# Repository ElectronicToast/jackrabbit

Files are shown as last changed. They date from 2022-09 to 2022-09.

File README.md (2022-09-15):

# jackrabbit

 

RP2040 16-channel 100 MHz logic analyzer

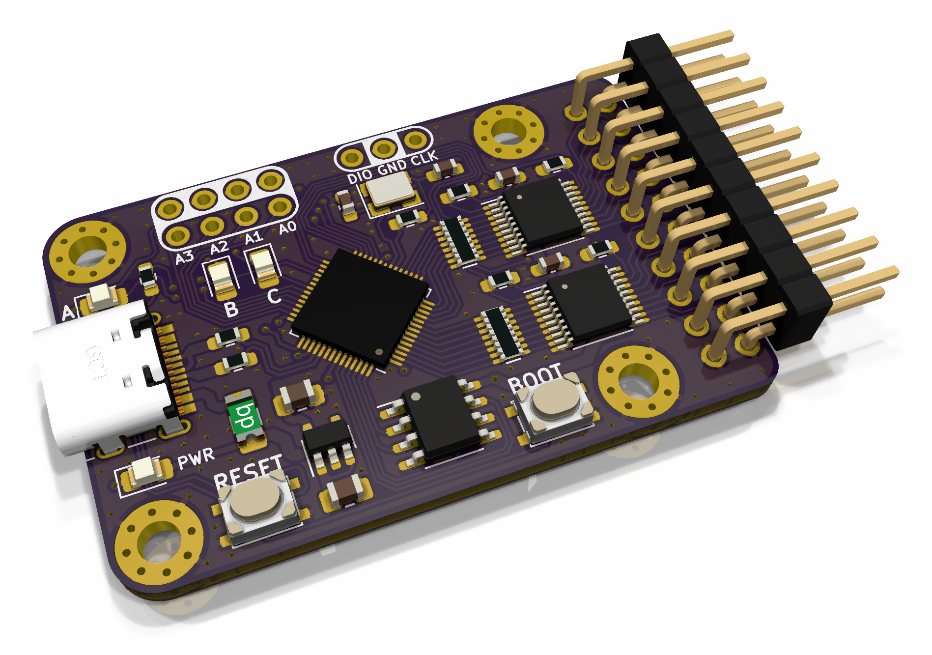
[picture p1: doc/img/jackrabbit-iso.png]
iso


## Description
Jackrabbit is a RP2040-based 16-channel logic analyzer in a tiny 1.8" by 1.2" form factor. All digital inputs are buffered for compatibility with both 3V3 and 5V logic. Boot mode select and reset buttons are provided for convenience, and the ADC inputs and SWD pins are broken out. A USB-C connector is present for firmware updates and serial data.

## Documentation
- [Schematic](https://github.com/ElectronicToast/jackrabbit/blob/main/doc/jackrabbit.pdf)
- Fab print [front](https://github.com/ElectronicToast/jackrabbit/blob/main/doc/jackrabbit-f.pdf) and [back](https://github.com/ElectronicToast/jackrabbit/blob/main/doc/jackrabbit-b.pdf)
- [Interactive BOM](http://htmlpreview.github.io/?https://github.com/ElectronicToast/jackrabbit/blob/main/doc/ibom.html)

## Contributors
- Brian Cruz - BS EE, Caltech, 2023
- Brandon Gong - BS CECS, USC, 2024
- Ray Sun - BS EE, Caltech, 2020; PhD EE, USC, 2026

## Licensing
This project is released under the terms of the MIT License.

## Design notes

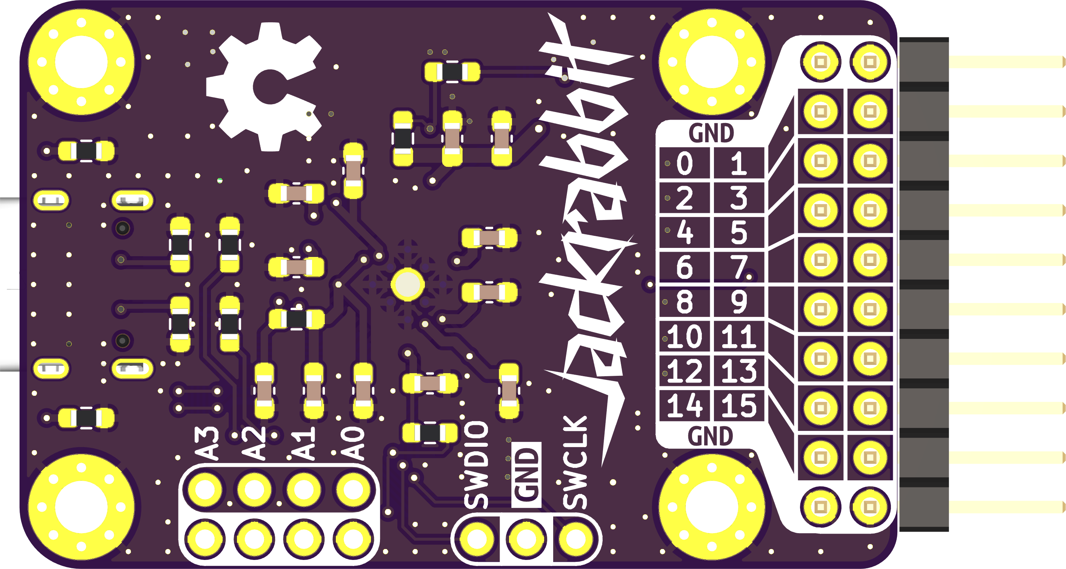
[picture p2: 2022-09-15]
doc/img/jackrabbit-b.png

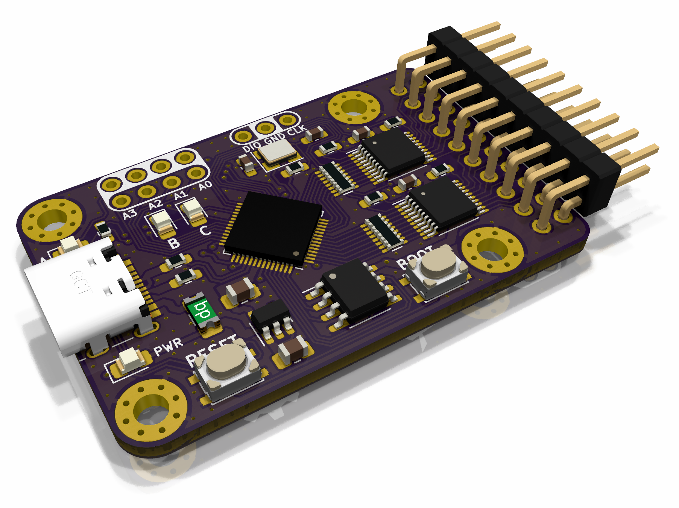
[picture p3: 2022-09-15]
doc/img/jackrabbit-iso1.png

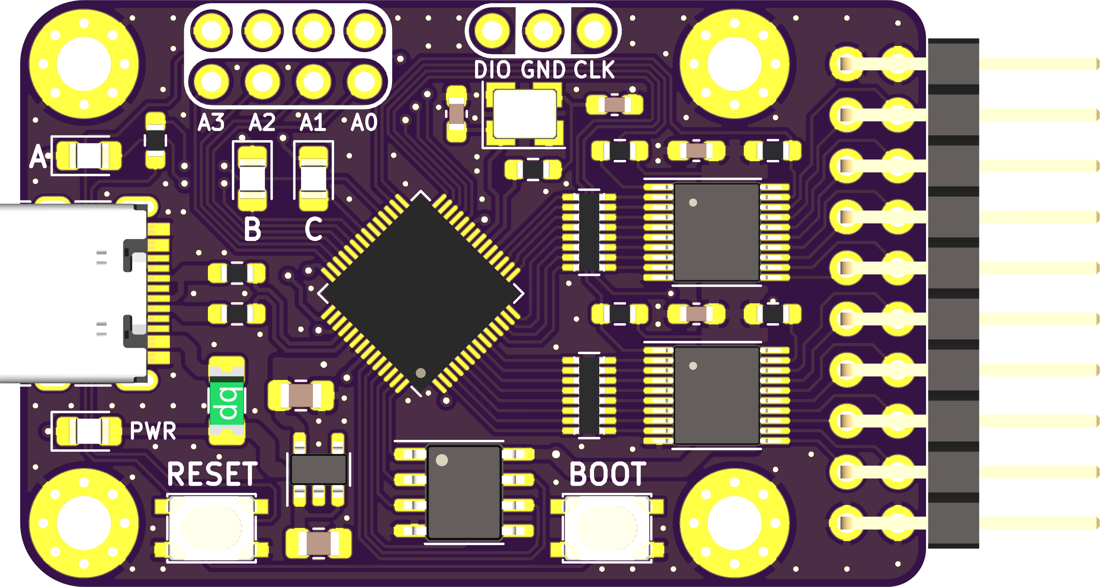
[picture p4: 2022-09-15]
doc/img/jackrabbit-f.png

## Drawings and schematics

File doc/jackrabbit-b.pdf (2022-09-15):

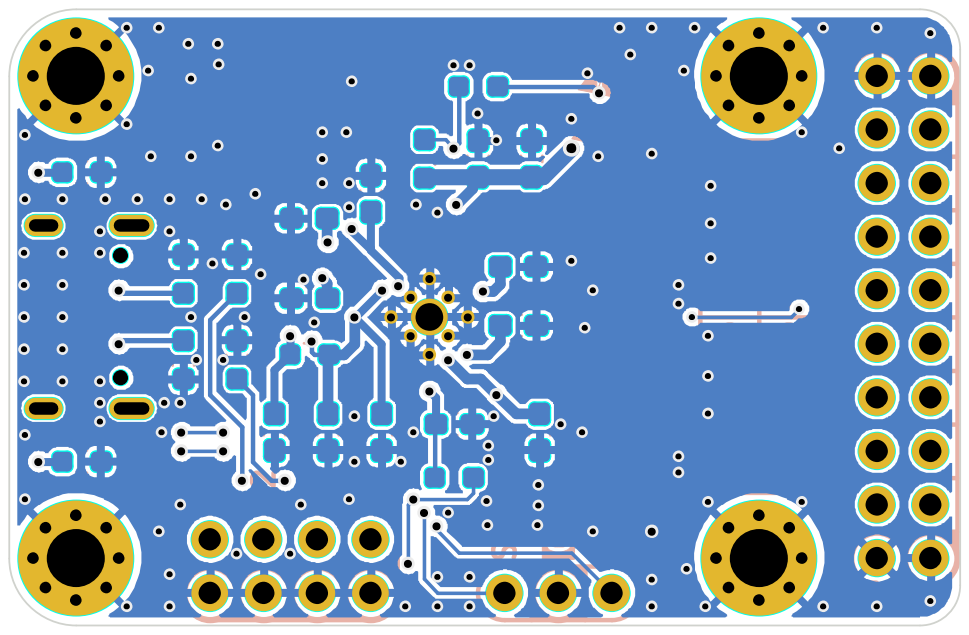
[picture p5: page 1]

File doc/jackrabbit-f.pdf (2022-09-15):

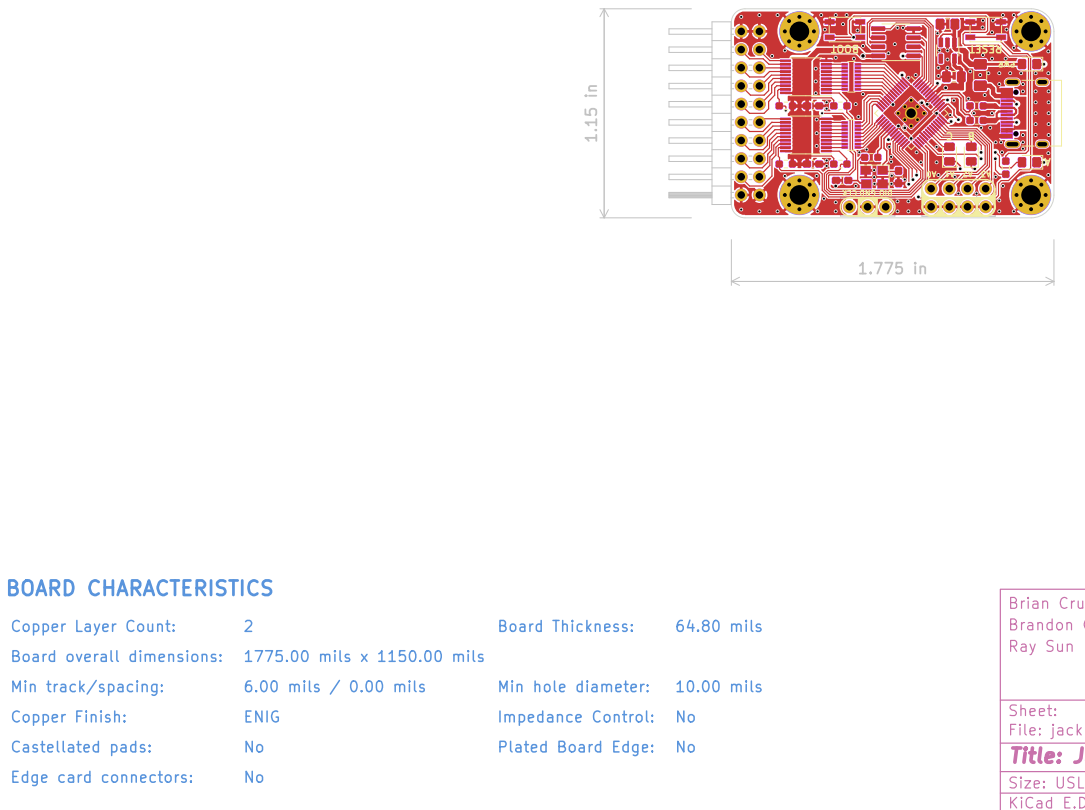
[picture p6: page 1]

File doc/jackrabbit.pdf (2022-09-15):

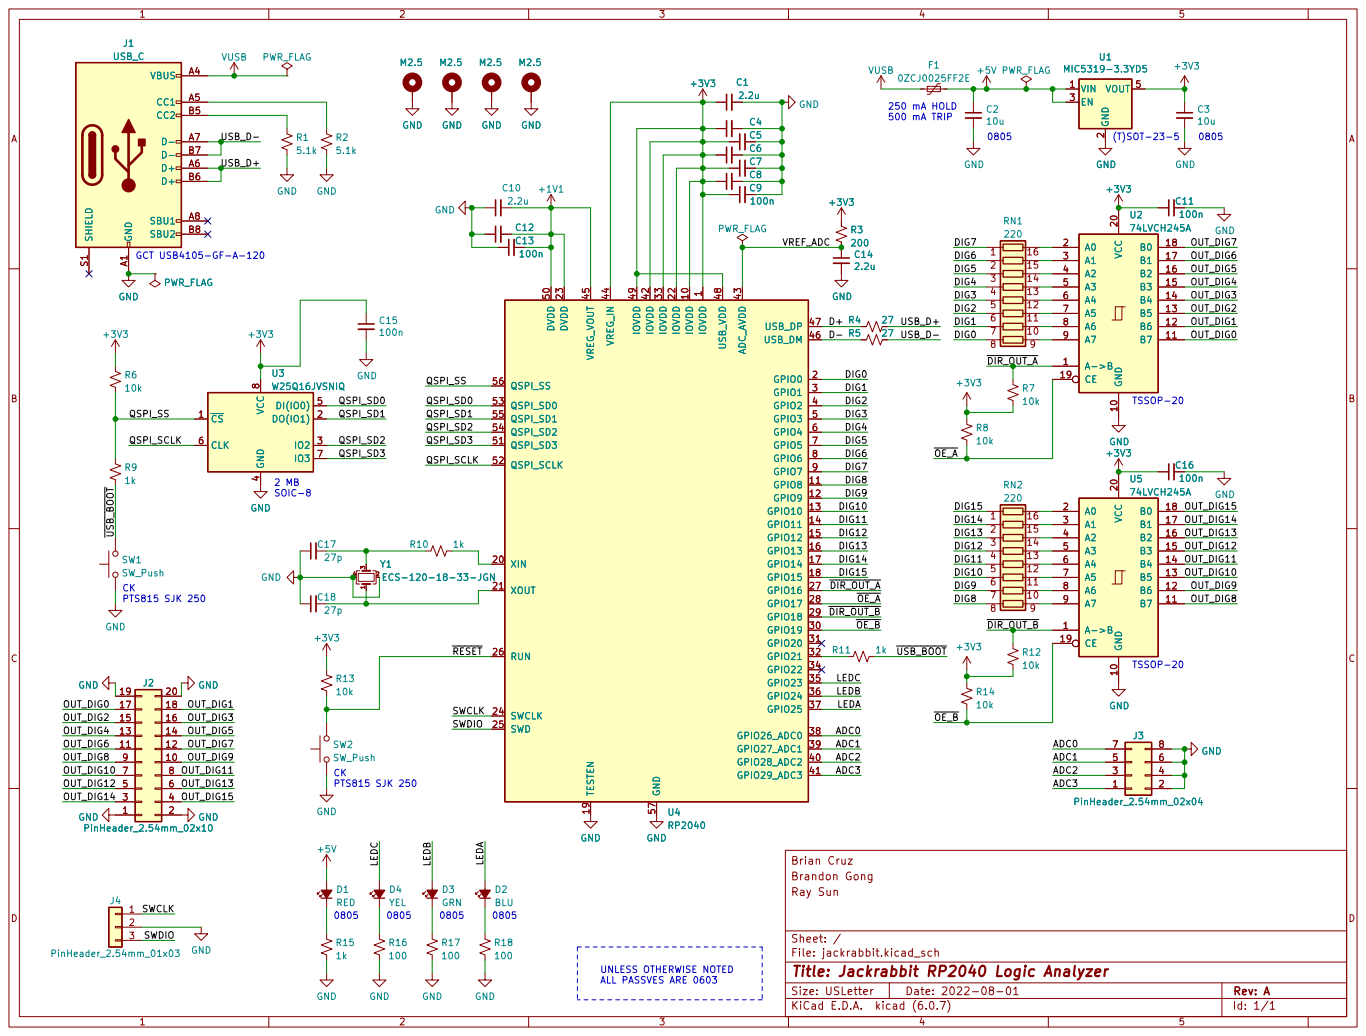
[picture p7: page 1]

1 IOVDD 10 GPIO8 11 GPIO9 12 GPIO10 13 GPIO11 14 GPIO12 15 GPIO13 16 GPIO14 17 GPIO15 18 TESTEN 19 GPIO0 2 XIN 20 XOUT 21 IOVDD 22 DVDD 23 SWCLK 24 SWD 25 RUN 26 GPIO16 27 GPIO17 28 GPIO18 29 GPIO1 3 GPIO19 30 GPIO20 31 GPIO21 32 IOVDD 33 GPIO22 34 GPIO23 35 GPIO24 36 GPIO25 37 GPIO26_ADC0 38 GPIO27_ADC1 39 GPIO2 4 GPIO28_ADC2 40 GPIO29_ADC3 41 IOVDD 42 ADC_AVDD 43 VREG_IN 44 VREG_VOUT 45 USB_DM 46 USB_DP 47 USB_VDD 48 IOVDD 49 GPIO3 5 DVDD 50 QSPI_SD3 51 QSPI_SCLK 52 QSPI_SD0 53 QSPI_SD2 54 QSPI_SD1 55 QSPI_SS 56 GND 57 GPIO4 6 GPIO5 7 GPIO6 8 GPIO7 9 U4RP2040 DIG9 ADC3 OUT_DIG15 ADC2 DIG15 DIG11 DIG10 OUT_DIG10 OUT_DIG9 OUT_DIG8 USB_D+ D- D+ OUT_DIG13 OUT_DIG14 OUT_DIG11 OUT_DIG12 DIG0 USB_D- OUT_DIG0 DIG7 DIG8 DIG9 ~{OE_A} DIG5 DIG6 DIG3 DIG2 DIG4 DIG1 DIG0 ~{DIR_OUT_A} DIG1 DIG11 DIG14 ~{DIR_OUT_B} DIG15 OUT_DIG0 SWDIO

1 IOVDD 10 GPIO8 11 GPIO9 12 GPIO10 13 GPIO11 14 GPIO12 15 GPIO13 16 GPIO14 17 GPIO15 18 TESTEN 19 GPIO0 2 XIN 20 XOUT 21 IOVDD 22 DVDD 23 SWCLK 24 SWD 25 RUN 26 GPIO16 27 GPIO17 28 GPIO18 29 GPIO1 3 GPIO19 30 GPIO20 31 GPIO21 32 IOVDD 33 GPIO22 34 GPIO23 35 GPIO24 36 GPIO25 37 GPIO26_ADC0 38 GPIO27_ADC1 39 GPIO2 4 GPIO28_ADC2 40 GPIO29_ADC3 41 IOVDD 42 ADC_AVDD 43 VREG_IN 44 VREG_VOUT 45 USB_DM 46 USB_DP 47 USB_VDD 48 IOVDD 49 GPIO3 5 DVDD 50 QSPI_SD3 51 QSPI_SCLK 52 QSPI_SD0 53 QSPI_SD2 54 QSPI_SD1 55 QSPI_SS 56 GND 57 GPIO4 6 GPIO5 7 GPIO6 8 GPIO7 9 Y1 ECS-120-18-33-JGN

Brandon Gong Brian Cruz

File: jackrabbit.kicad_sch Sheet: / Ray Sun

Id: 1/1 Title: Jackrabbit RP2040 Logic Analyzer

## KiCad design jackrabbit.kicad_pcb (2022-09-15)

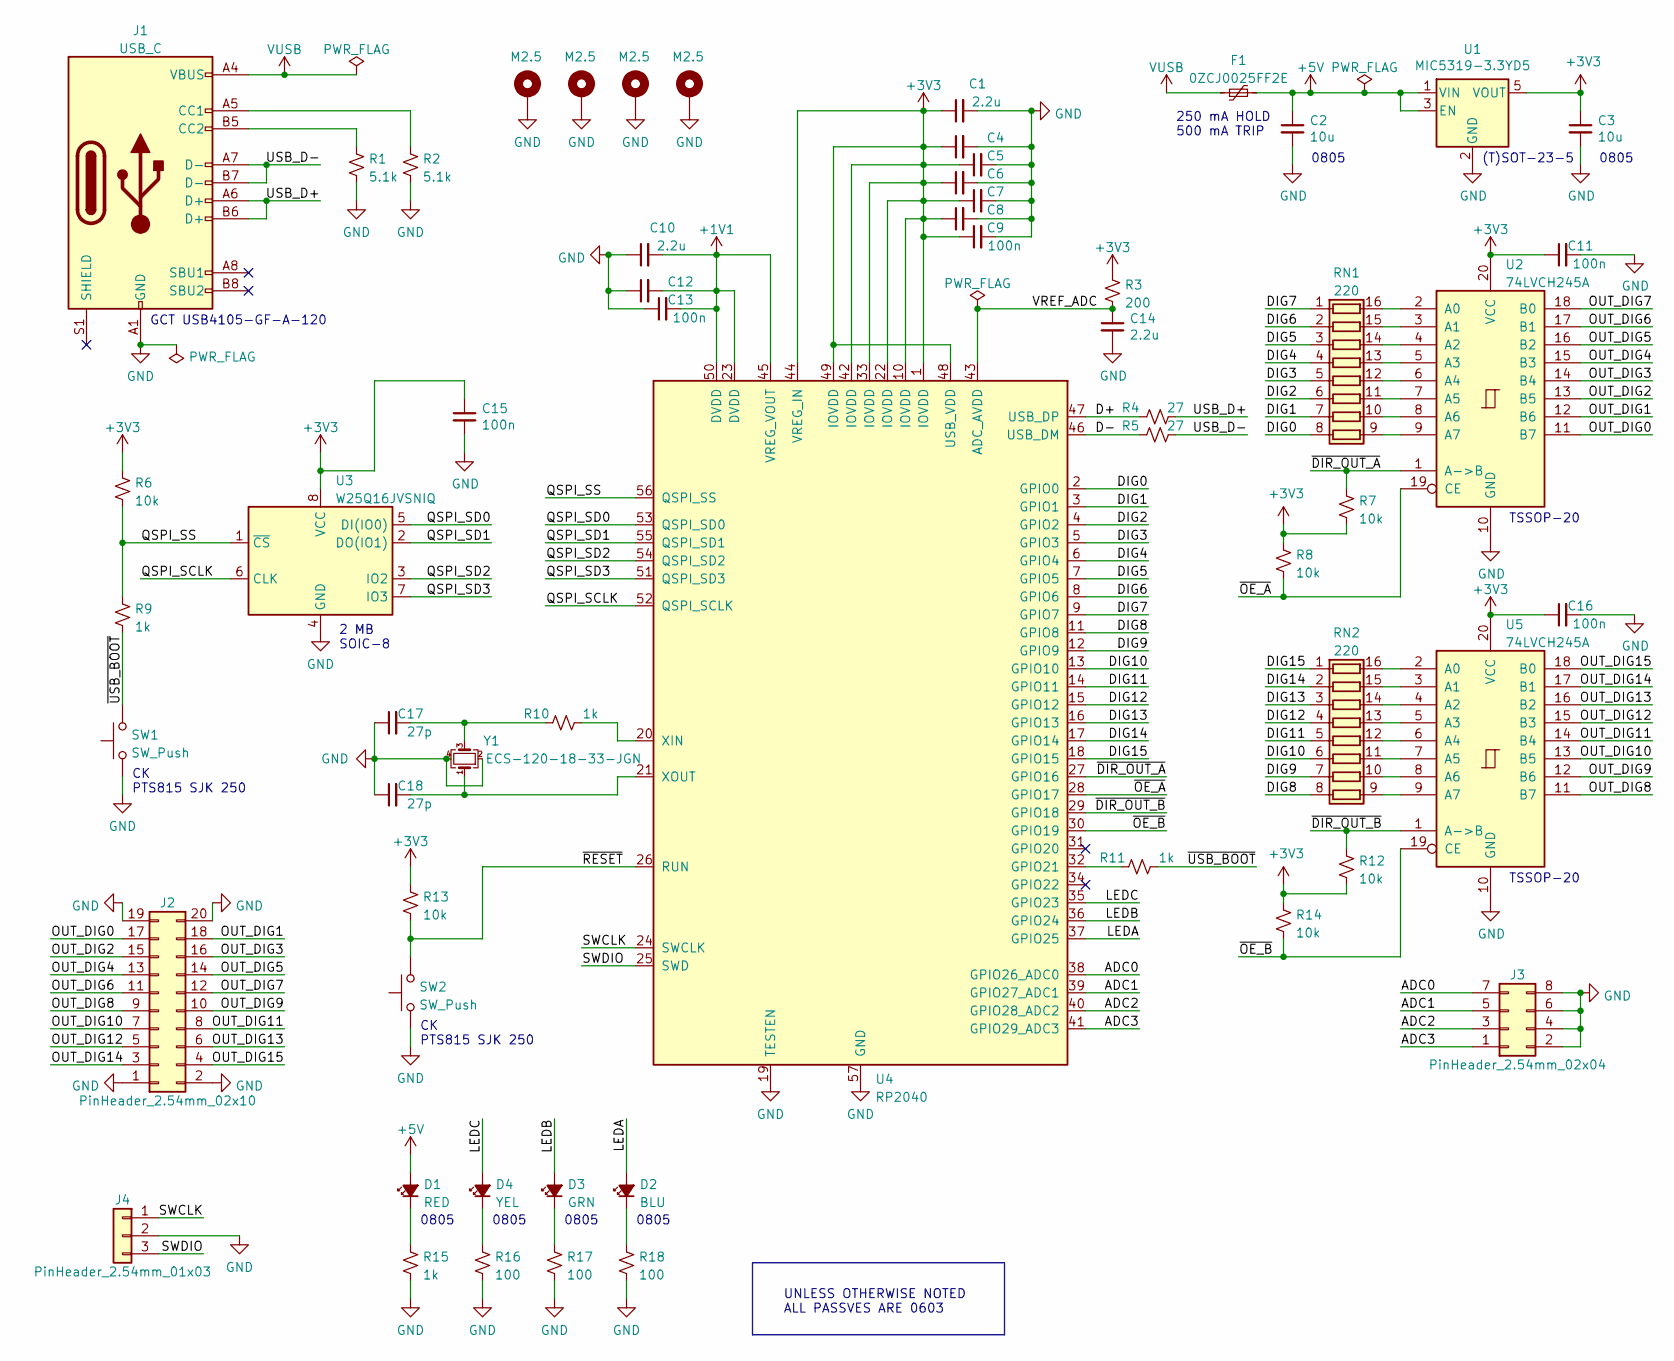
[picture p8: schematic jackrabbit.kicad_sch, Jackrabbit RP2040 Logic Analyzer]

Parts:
C1, C10, C14: 2.2u; C_0603_1608Metric_Pad1.08x0.95mm_HandSolder
C2, C3: 10u; C_0805_2012Metric_Pad1.18x1.45mm_HandSolder
C4, C5, C6, C7, C8, C9, C11, C12, C13, C15, C16: 100n; C_0603_1608Metric_Pad1.08x0.95mm_HandSolder
C17, C18: 27p; C_0603_1608Metric_Pad1.08x0.95mm_HandSolder
D1: RED; LED_0805_2012Metric_Pad1.15x1.40mm_HandSolder
D2: BLU; LED_0805_2012Metric_Pad1.15x1.40mm_HandSolder
D3: GRN; LED_0805_2012Metric_Pad1.15x1.40mm_HandSolder
D4: YEL; LED_0805_2012Metric_Pad1.15x1.40mm_HandSolder
F1: 0ZCJ0025FF2E; Fuse_1206_3216Metric_Pad1.42x1.75mm_HandSolder
H1, H2, H3, H4: M2.5; MountingHole_2.7mm_M2.5_Pad_Via
J1: USB_C; USB_C_Receptacle_GCT_USB4105-GF-A-120
J2: PinHeader_2.54mm_02x10; PinHeader_2x10_P2.54mm_Horizontal_NoSilk
J3: PinHeader_2.54mm_02x04; PinHeader_2x04_P2.54mm_NoSilk
J4: PinHeader_2.54mm_01x03; PinHeader_1x03_P2.54mm_NoSilk
R1, R2: 5.1k; R_0603_1608Metric_Pad0.98x0.95mm_HandSolder
R3: 200; R_0603_1608Metric_Pad0.98x0.95mm_HandSolder
R4, R5: 27; R_0603_1608Metric_Pad0.98x0.95mm_HandSolder
R6, R7, R8, R12, R13, R14: 10k; R_0603_1608Metric_Pad0.98x0.95mm_HandSolder
R9, R10, R11, R15: 1k; R_0603_1608Metric_Pad0.98x0.95mm_HandSolder
R16, R17, R18: 100; R_0603_1608Metric_Pad0.98x0.95mm_HandSolder
RN1, RN2: 220; R_Array_Convex_8x0602
SW1, SW2: SW_Push; SW_Push_CK_PTS815_HandSoldering
U1: MIC5319-3.3YD5; SOT-23-5
U2, U5: 74LVCH245A; TSSOP-20_4.4x5mm_P0.5mm
U3: W25Q16JVSNIQ; SOIC-8_3.9x4.9mm_P1.27mm
U4: RP2040; RP2040-QFN-56_HandSoldering
Y1: ECS-120-18-33-JGN; Crystal_SMD_ECS-4Pin_3.2x2.5mm

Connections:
+1V1: C10.2, C12.2, C13.2, U4.23 (DVDD), U4.45 (VREG_VOUT), U4.50 (DVDD)
+3V3: C1.1, C3.1, C4.1, C5.1, C6.1, C7.1, C8.1, C9.1, C11.1, C15.1, C16.1, R3.1, R6.1, R7.2, R8.1, R12.2, R13.1, R14.1, U1.5 (VOUT), U2.20 (VCC), U3.8 (VCC), U4.1 (IOVDD), U4.10 (IOVDD), U4.22 (IOVDD), U4.33 (IOVDD), U4.42 (IOVDD), U4.44 (VREG_IN), U4.48 (USB_VDD), U4.49 (IOVDD), U5.20 (VCC)
+5V: C2.1, D1.2 (A), F1.2, U1.1 (VIN), U1.3 (EN)
/ADC0: J3.7, U4.38 (GPIO26_ADC0)
/ADC1: J3.5, U4.39 (GPIO27_ADC1)
/ADC2: J3.3, U4.40 (GPIO28_ADC2)
/ADC3: J3.1, U4.41 (GPIO29_ADC3)
/D+: R4.1, U4.47 (USB_DP)
/D-: R5.1, U4.46 (USB_DM)
/DIG0: RN1.8 (R8.1), U4.2 (GPIO0)
/DIG1: RN1.7 (R7.1), U4.3 (GPIO1)
/DIG2: RN1.6 (R6.1), U4.4 (GPIO2)
/DIG3: RN1.5 (R5.1), U4.5 (GPIO3)
/DIG4: RN1.4 (R4.1), U4.6 (GPIO4)
/DIG5: RN1.3 (R3.1), U4.7 (GPIO5)
/DIG6: RN1.2 (R2.1), U4.8 (GPIO6)
/DIG7: RN1.1 (R1.1), U4.9 (GPIO7)
/DIG8: RN2.8 (R8.1), U4.11 (GPIO8)
/DIG9: RN2.7 (R7.1), U4.12 (GPIO9)
/DIG10: RN2.6 (R6.1), U4.13 (GPIO10)
/DIG11: RN2.5 (R5.1), U4.14 (GPIO11)
/DIG12: RN2.4 (R4.1), U4.15 (GPIO12)
/DIG13: RN2.3 (R3.1), U4.16 (GPIO13)
/DIG14: RN2.2 (R2.1), U4.17 (GPIO14)
/DIG15: RN2.1 (R1.1), U4.18 (GPIO15)
/LEDA: D2.2 (A), U4.37 (GPIO25)
/LEDB: D3.2 (A), U4.36 (GPIO24)
/LEDC: D4.2 (A), U4.35 (GPIO23)
/OUT_DIG0: J2.17, U2.11 (B7)
/OUT_DIG1: J2.18, U2.12 (B6)
/OUT_DIG2: J2.15, U2.13 (B5)
/OUT_DIG3: J2.16, U2.14 (B4)
/OUT_DIG4: J2.13, U2.15 (B3)
/OUT_DIG5: J2.14, U2.16 (B2)
/OUT_DIG6: J2.11, U2.17 (B1)
/OUT_DIG7: J2.12, U2.18 (B0)
/OUT_DIG8: J2.9, U5.11 (B7)
/OUT_DIG9: J2.10, U5.12 (B6)
/OUT_DIG10: J2.7, U5.13 (B5)
/OUT_DIG11: J2.8, U5.14 (B4)
/OUT_DIG12: J2.5, U5.15 (B3)
/OUT_DIG13: J2.6, U5.16 (B2)
/OUT_DIG14: J2.3, U5.17 (B1)
/OUT_DIG15: J2.4, U5.18 (B0)
/QSPI_SCLK: U3.6 (CLK), U4.52 (QSPI_SCLK)
/QSPI_SD0: U3.5 (DI(IO0)), U4.53 (QSPI_SD0)
/QSPI_SD1: U3.2 (DO(IO1)), U4.55 (QSPI_SD1)
/QSPI_SD2: U3.3 (IO2), U4.54 (QSPI_SD2)
/QSPI_SD3: U3.7 (IO3), U4.51 (QSPI_SD3)
/QSPI_SS: R6.2, R9.1, U3.1 (~CS), U4.56 (QSPI_SS)
/SWCLK: J4.1, U4.24 (SWCLK)
/SWDIO: J4.3, U4.25 (SWD)
/USB_D+: J1.A6 (D+), J1.B6 (D+), R4.2
/USB_D-: J1.A7 (D-), J1.B7 (D-), R5.2
/VREF_ADC: C14.1, R3.2, U4.43 (ADC_AVDD)
/~DIR_OUT_A: R7.1, U2.1 (A->B), U4.27 (GPIO16)
/~DIR_OUT_B: R12.1, U4.29 (GPIO18), U5.1 (A->B)
/~OE_A: R8.2, U2.19 (CE), U4.28 (GPIO17)
/~OE_B: R14.2, U4.30 (GPIO19), U5.19 (CE)
/~RESET: R13.2, SW2.2, U4.26 (RUN)
/~USB_BOOT: R9.2, R11.2, SW1.2
GND: C1.2, C2.2, C3.2, C4.2, C5.2, C6.2, C7.2, C8.2, C9.2, C10.1, C11.2, C12.1, C13.1, C14.2, C15.2, C16.2, C17.1, C18.1, H1.1, H2.1, H3.1, H4.1, J1.A1 (GND), J1.A12 (GND), J1.B1 (GND), J1.B12 (GND), J2.1, J2.2, J2.19, J2.20, J3.2, J3.4, J3.6, J3.8, J4.2, R1.2, R2.2, R15.2, R16.2, R17.2, R18.2, SW1.1, SW2.1, U1.2 (GND), U2.10 (GND), U3.4 (GND), U4.19 (TESTEN), U4.57 (GND), U5.10 (GND), Y1.2, Y1.4
unnamed: C17.2, R10.1, Y1.3
unnamed: C18.2, U4.21 (XOUT), Y1.1
unnamed: D1.1 (K), R15.1
unnamed: D2.1 (K), R18.1
unnamed: D3.1 (K), R17.1
unnamed: D4.1 (K), R16.1
unnamed: J1.A5 (CC1), R2.1
unnamed: J1.B5 (CC2), R1.1
unnamed: R10.2, U4.20 (XIN)
unnamed: R11.1, U4.32 (GPIO21)
unnamed: RN1.9 (R8.2), U2.9 (A7)
unnamed: RN1.10 (R7.2), U2.8 (A6)
unnamed: RN1.11 (R6.2), U2.7 (A5)
unnamed: RN1.12 (R5.2), U2.6 (A4)
unnamed: RN1.13 (R4.2), U2.5 (A3)
unnamed: RN1.14 (R3.2), U2.4 (A2)
unnamed: RN1.15 (R2.2), U2.3 (A1)
unnamed: RN1.16 (R1.2), U2.2 (A0)
unnamed: RN2.9 (R8.2), U5.9 (A7)
unnamed: RN2.10 (R7.2), U5.8 (A6)
unnamed: RN2.11 (R6.2), U5.7 (A5)
unnamed: RN2.12 (R5.2), U5.6 (A4)
unnamed: RN2.13 (R4.2), U5.5 (A3)
unnamed: RN2.14 (R3.2), U5.4 (A2)
unnamed: RN2.15 (R2.2), U5.3 (A1)
unnamed: RN2.16 (R1.2), U5.2 (A0)
VUSB: F1.1, J1.A4 (VBUS), J1.A9 (VBUS), J1.B4 (VBUS), J1.B9 (VBUS)

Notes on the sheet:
0805
CK PTS815 SJK 250
2 MB SOIC-8
UNLESS OTHERWISE NOTED ALL PASSVES ARE 0603
GCT USB4105-GF-A-120
250 mA HOLD 500 mA TRIP
TSSOP-20
(T)SOT-23-5

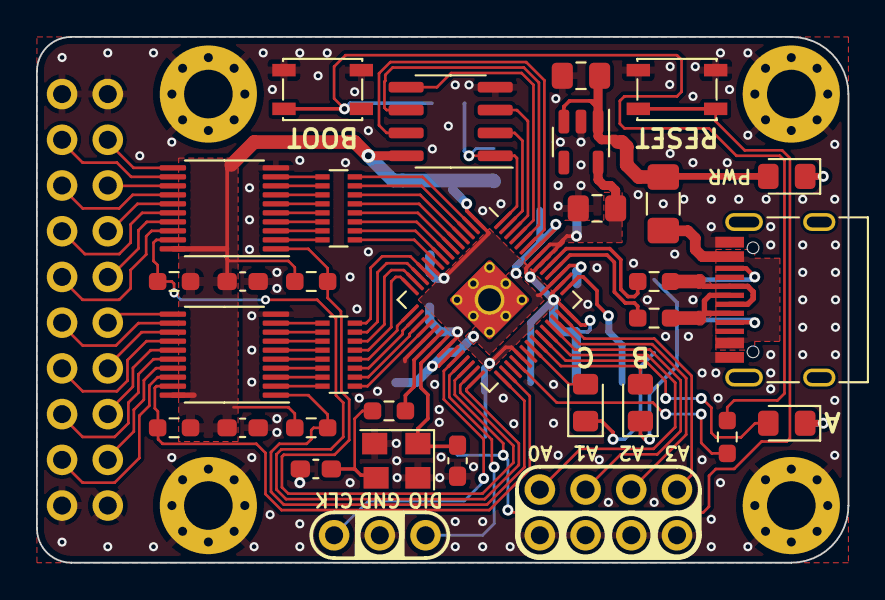
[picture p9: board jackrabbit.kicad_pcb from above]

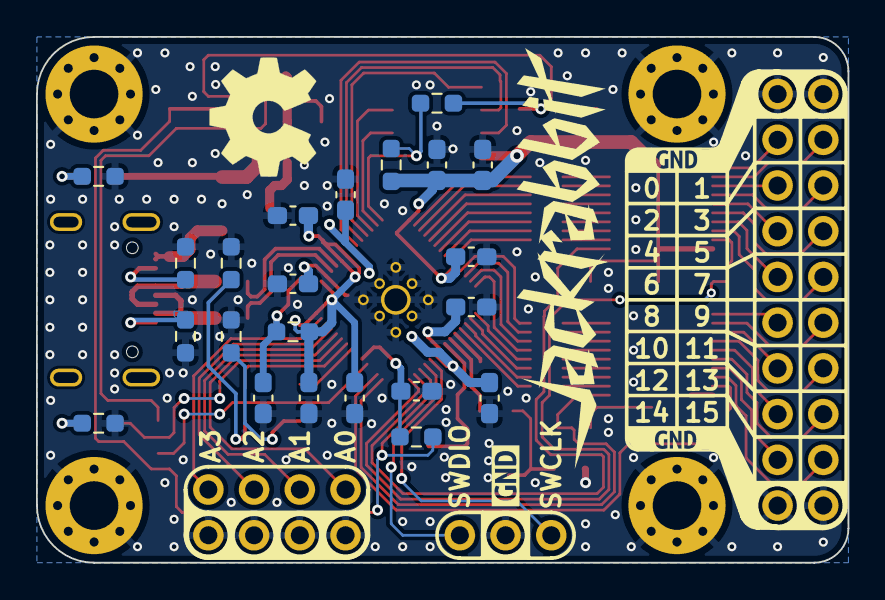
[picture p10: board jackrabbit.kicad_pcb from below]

Board: 2 copper layers, 45.1 x 29.2 mm, 63 parts (26 on the bottom side), 89 nets.

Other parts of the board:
kibuzzard-62E7A97F: G***; kibuzzard-62E7A97F
kibuzzard-62E7AE0F: G***; kibuzzard-62E7AE0F
kibuzzard-62E8C5F1, kibuzzard-62E8C5F1#2: G***; kibuzzard-62E8C5F1

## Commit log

2022-07-17 Add bus contention series protection resistors
    [jackrabbit.kicad_pcb, jackrabbit.kicad_sch]
2022-07-17 Start layout with passives on bottom
    [jackrabbit.kicad_pcb, jackrabbit.kicad_sch]
2022-07-17 Squeeze buffers together to lower board width
    [jackrabbit.kicad_pcb]
2022-07-22 Add pullups to disable buffers on power-on
    [jackrabbit.kicad_pcb, jackrabbit.kicad_sch]
2022-07-25 Redo placement to put USB and digital connector on long axis
    [jackrabbit.kicad_pcb, jackrabbit.kicad_sch]
2022-07-25 Change footprints to those of ordered parts
    [jackrabbit.kicad_pcb, jackrabbit.kicad_sch]
2022-07-26 Continue layout
    [jackrabbit.kicad_pcb, jackrabbit.kicad_sch]
2022-08-01 Continue layout; add labels for digital connector
    [jackrabbit.kicad_pcb, jackrabbit.kicad_sch]
2022-08-01 Add logos and connector labels
    [jackrabbit.kicad_pcb]
2022-08-01 Connect bootsel button to a GPIO; remove connectors for which we have no room
    [jackrabbit.kicad_pcb, jackrabbit.kicad_sch]
2022-08-02 Continue layout; prettify digital connector labels
    [jackrabbit.kicad_pcb]
2022-08-02 Flip LED labels to make 'A" the one by the USB connector
    [jackrabbit.kicad_pcb, jackrabbit.kicad_sch]
2022-08-11 Finish routing all traces
    [jackrabbit.kicad_pcb]
2022-08-12 Pass DRC
    [jackrabbit.kicad_pcb]
2022-09-13 Fix unconnected track end DRC warnings
    [jackrabbit.kicad_pcb]
2022-09-13 Replace 74LCX245 with 74LVCH245A for bus hold to prevent floating input
    [jackrabbit.kicad_pcb, jackrabbit.kicad_sch]
2022-09-13 Clean up board setup, increase thermal relief gap on THT pads
    [jackrabbit.kicad_pcb]
2022-09-15 Fix sheet and add OSHpark stackup info
    [jackrabbit.kicad_pcb]
2022-09-15 Fix pcb file for OSHpark
    [jackrabbit.kicad_pcb]
2022-09-15 Make crystal footprint; check footprints
    [jackrabbit.kicad_pcb, jackrabbit.kicad_sch]
2022-09-15 Generate ibon
    [jackrabbit.kicad_pcb]
